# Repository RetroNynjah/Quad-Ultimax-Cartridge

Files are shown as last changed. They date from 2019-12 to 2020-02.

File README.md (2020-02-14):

# Retro Ninja Quad Ultimax Cartridge

Eagle schematics and board for a C64 Ultimax cartridge with two-bit ROM selector DIP switch (or jumpers). It's based on a 27256 type EPROM and can fit four 64Kbit (8KB) Ultimax ROM images.

Combine up to four 8KB ROM files into one bigger file before burning EPROM.

 

The DIP switch is optional. Leave it out if all you need is one 8KB ROM. The DIP switch can also be replaced by a couple of jumpers.

Gerber files and 3D-printable enclosure included.

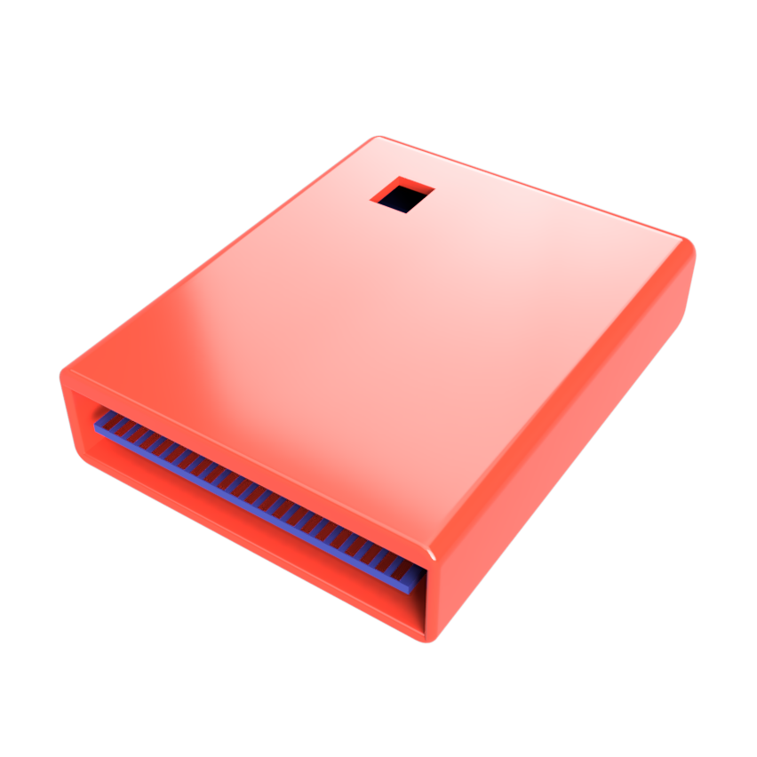
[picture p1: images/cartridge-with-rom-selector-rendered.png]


## BOM
 |Component|Pcs |Name|Comment|
 |:--------|---:|:---|:------|
 | 27256/27C256 EPROM DIP-28| 1 | IC1 | Or compatible EPROM |
 | 2-pos dip switch | 1 | BT1| Optional. CT2062-ND from Digikey or similar | 
 | 100nF ceramic capacitor | 1 | C1 ||
 | 10k resistor | 2 | R1, R2 ||
 
Retro Ninja

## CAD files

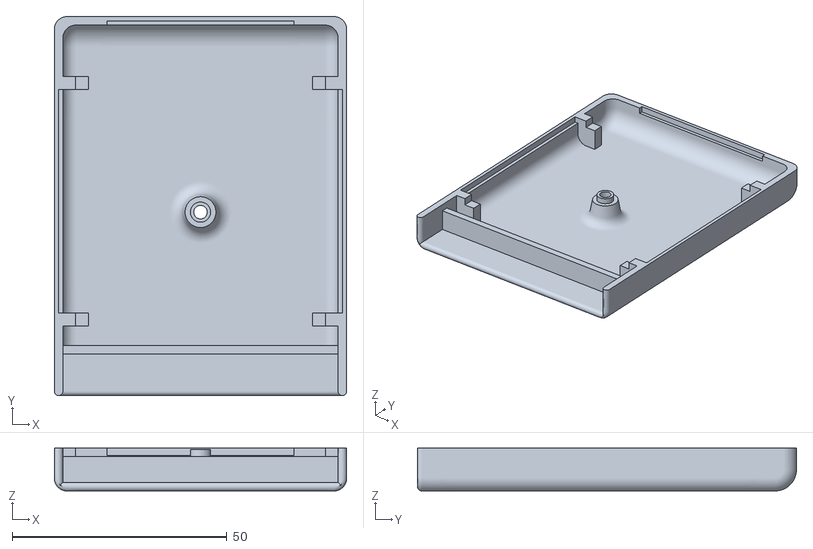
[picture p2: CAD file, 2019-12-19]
enclosure/cartridge-bottom.stl
68.0 x 88.1 x 10.0

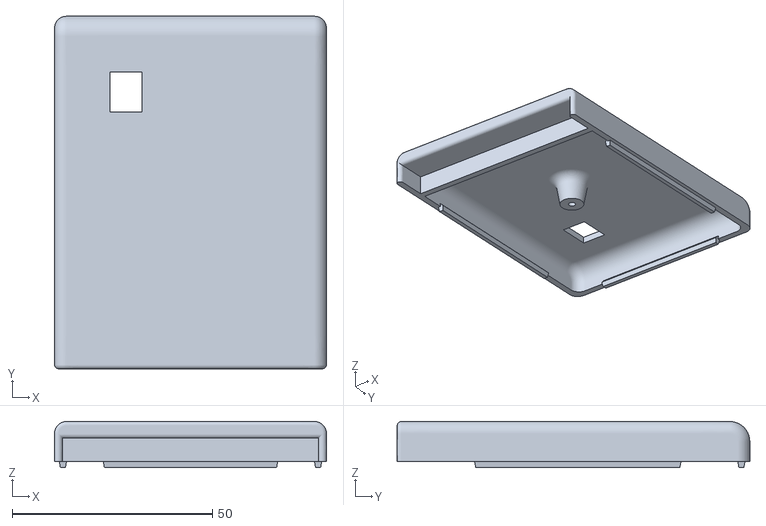
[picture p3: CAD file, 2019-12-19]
enclosure/cartridge-top-with-rom-selector.stl
68.0 x 88.1 x 11.5

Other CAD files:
enclosure/cartridge-top.stl

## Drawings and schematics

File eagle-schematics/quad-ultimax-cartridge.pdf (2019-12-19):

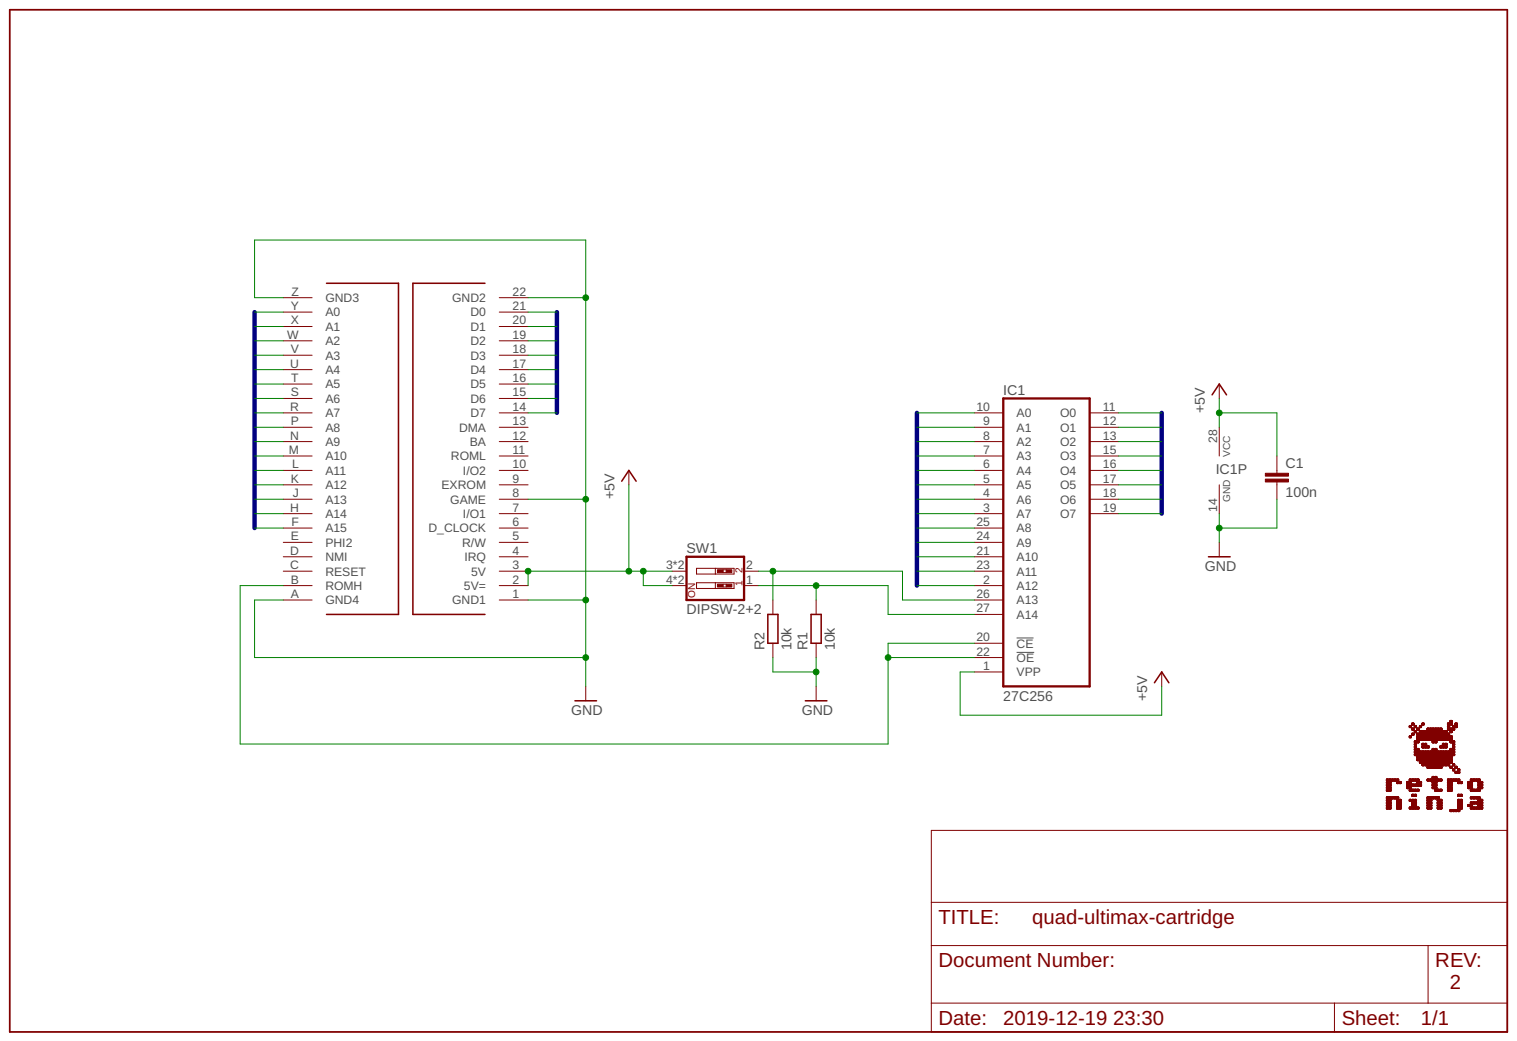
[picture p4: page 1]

+5V GND GND 27C256 +5V 10k 10k GND +5V 100n DIPSW-2+2 GND3 Z A0 Y A1 X A2 W A3 V A4 U A5 T A6 S A7 R A8 P A9 N A10 M A11 L A12 K A13 J A14 H A15 F PHI2 E NMI D RESET C ROMH B GND4 A GND2 22 D0 21 D1 20 D2 19 D3 18 D4 17 D5 16 D6 15 D7 14 DMA 13 BA 12 ROML 11 I/O2 10 EXROM 9 GAME 8 I/O1 7 D_CLOCK 6 R/W 5 IRQ 4 5V 3 5V= 2 GND1 1 VPP 1 A12 2 A7 3 A6 4 A5 5 A4 6 A3 7 A2 8 A1 9 A0 10 O0 11 O1 12 O2 13 O3 15 O4 16 O5 17 O6 18 O7 19 CE 20 A10 21 OE 22 A11 23 A9 24 A8 25 A13 26 A14 27 IC1 GND VCC 14 28 IC1P R1 R2 C1 3*2 4*2 12 SW1 2 1 2 ON Date: Sheet: REV: TITLE: Document Number: 2019-12-19 23:30 1/1 quad-ultimax-cartridge

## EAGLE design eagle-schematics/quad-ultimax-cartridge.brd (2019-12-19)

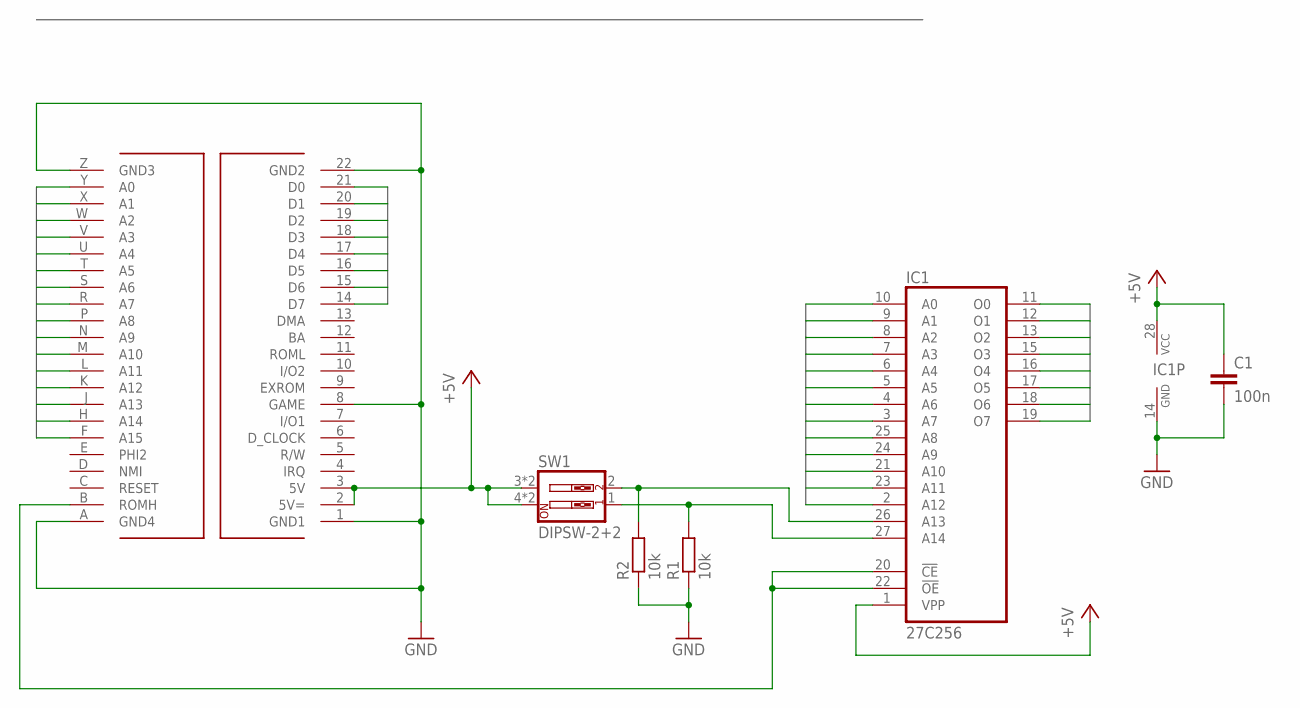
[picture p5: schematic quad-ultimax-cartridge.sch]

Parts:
C1: 100n; CAP_5MM_2.5X5.0_ROUND
IC1: 27C256; DIL28
R1, R2: 10k; 0207/10
SW1: DIPSW-2+2; DIPSW2+2
U$1: C64CARTRIDGE_BOARD_CONNECTOR; C64_CARTRIDGE_BOARDEDGE

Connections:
+5V: C1.1, IC1.1 (VPP), IC1.28 (VCC), SW1.3, SW1.4, SW1.5 (3), SW1.6 (4), U$1.2 (5V=), U$1.3 (5V)
A0: IC1.10 (A0), U$1.Y (A0)
A1: IC1.9 (A1), U$1.X (A1)
A2: IC1.8 (A2), U$1.W (A2)
A3: IC1.7 (A3), U$1.V (A3)
A4: IC1.6 (A4), U$1.U (A4)
A5: IC1.5 (A5), U$1.T (A5)
A6: IC1.4 (A6), U$1.S (A6)
A7: IC1.3 (A7), U$1.R (A7)
A8: IC1.25 (A8), U$1.P (A8)
A9: IC1.24 (A9), U$1.N (A9)
A10: IC1.21 (A10), U$1.M (A10)
A11: IC1.23 (A11), U$1.L (A11)
A12: IC1.2 (A12), U$1.K (A12)
A13: U$1.J (A13)
A14: U$1.H (A14)
A15: U$1.F (A15)
D0: IC1.11 (O0), U$1.21 (D0)
D1: IC1.12 (O1), U$1.20 (D1)
D2: IC1.13 (O2), U$1.19 (D2)
D3: IC1.15 (O3), U$1.18 (D3)
D4: IC1.16 (O4), U$1.17 (D4)
D5: IC1.17 (O5), U$1.16 (D5)
D6: IC1.18 (O6), U$1.15 (D6)
D7: IC1.19 (O7), U$1.14 (D7)
GND: C1.2, IC1.14 (GND), R1.1, R2.1, U$1.1 (GND1), U$1.8 (GAME), U$1.22 (GND2), U$1.A (GND4), U$1.Z (GND3)
unnamed: IC1.20 (!CE), IC1.22 (!OE), U$1.B (ROMH)
unnamed: IC1.26 (A13), R2.2, SW1.2
unnamed: IC1.27 (A14), R1.2, SW1.1

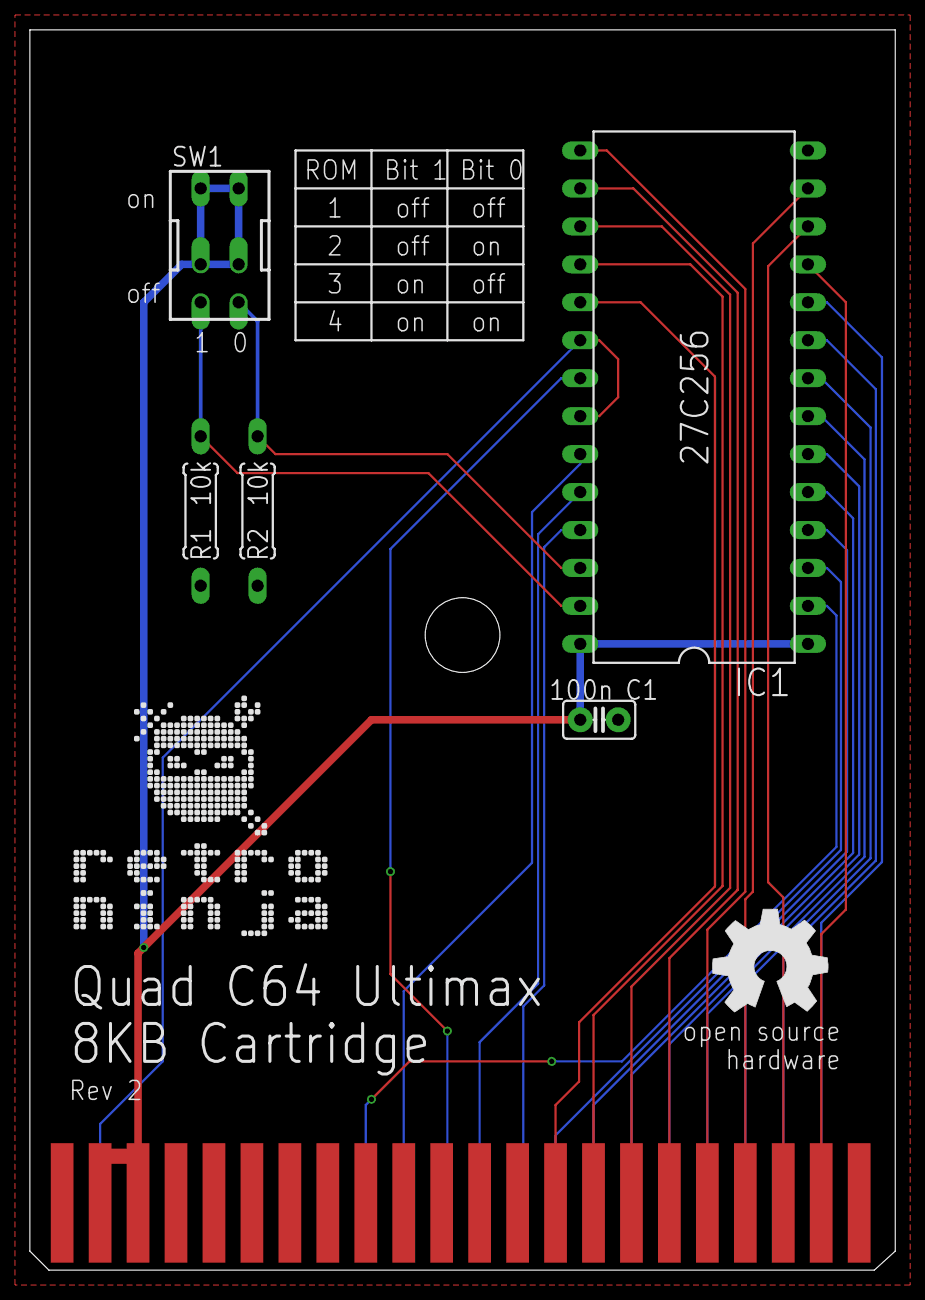
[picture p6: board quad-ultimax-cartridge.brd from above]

Board: 2 copper layers, 57.9 x 83.0 mm, 8 parts (0 on the bottom side), 26 nets.

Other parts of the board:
U$2: RETRONINJA_TEXT_17MM
U$3: OSHW_8MM

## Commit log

2019-12-19 added schematics, stl files and images
    [cartridge-bottom.stl, cartridge-top-with-rom-selector.stl, cartridge-top.stl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]
2019-12-19 Updated images and BOM
2019-12-19 Update schematics
    [quad-ultimax-cartridge.sch]
